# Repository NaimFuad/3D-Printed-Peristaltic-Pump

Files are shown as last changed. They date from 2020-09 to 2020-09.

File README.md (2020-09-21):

# 3D-Printed-Peristaltic-Pump
3D printed peristaltic pump intended for precise dosing of liquid

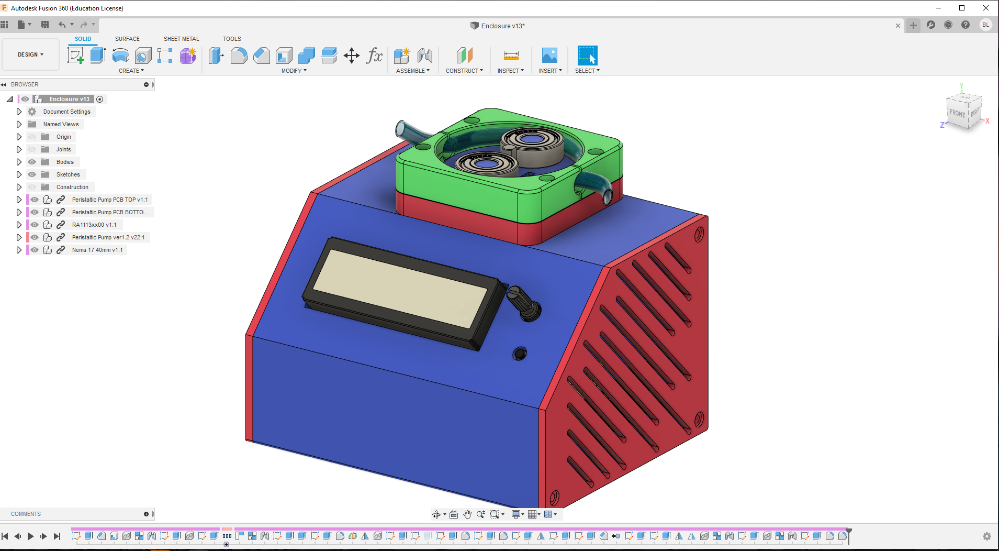
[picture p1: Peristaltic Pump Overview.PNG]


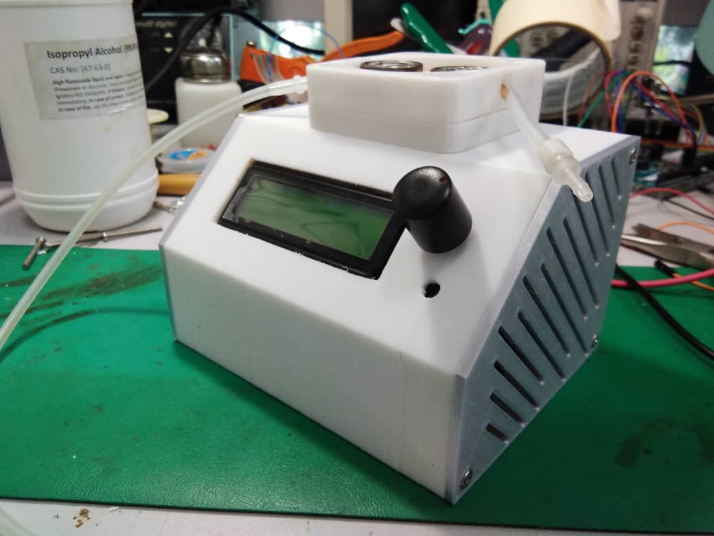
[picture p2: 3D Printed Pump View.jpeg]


[Video on how it work](https://youtu.be/wXhuivK0bVU)

Status - Work In Progress

The main idea of this project is to allow user to 3D print their own peristaltic pump. The pump able to micro dose liquid and the design allows it to self prime and avoid from bleeding.

An extension of this project can be applied to agricultural field where precise chemical might need to be introduce to plant from time to time.

## Hardware

* Frame - 3D Printed
* 608ZZ Bearing
* M3 Screw
* M3 Treaded Insert

## Electronics
* NEMA 17 Stepper Motor
* PCB - Fabricated from JLCPCB - footprint selected to allow user to hand solder
* A4988 Stepper Motor Driver
* etc. Refer to Bill of Material provided 

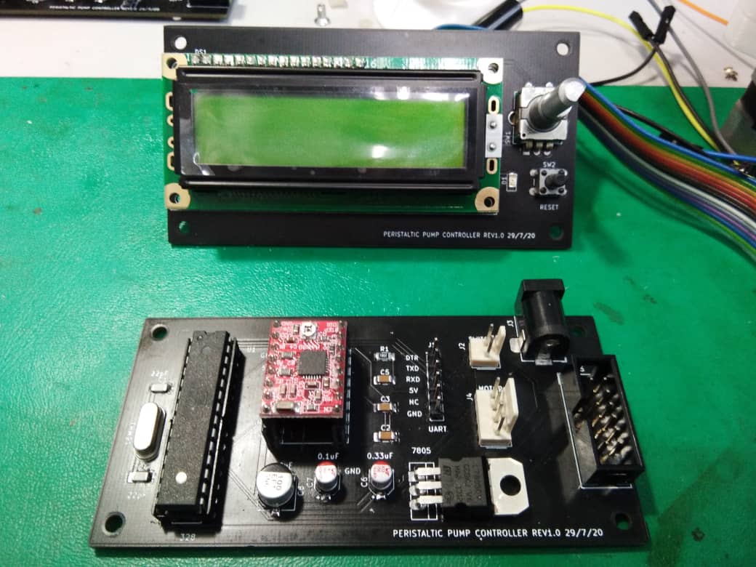
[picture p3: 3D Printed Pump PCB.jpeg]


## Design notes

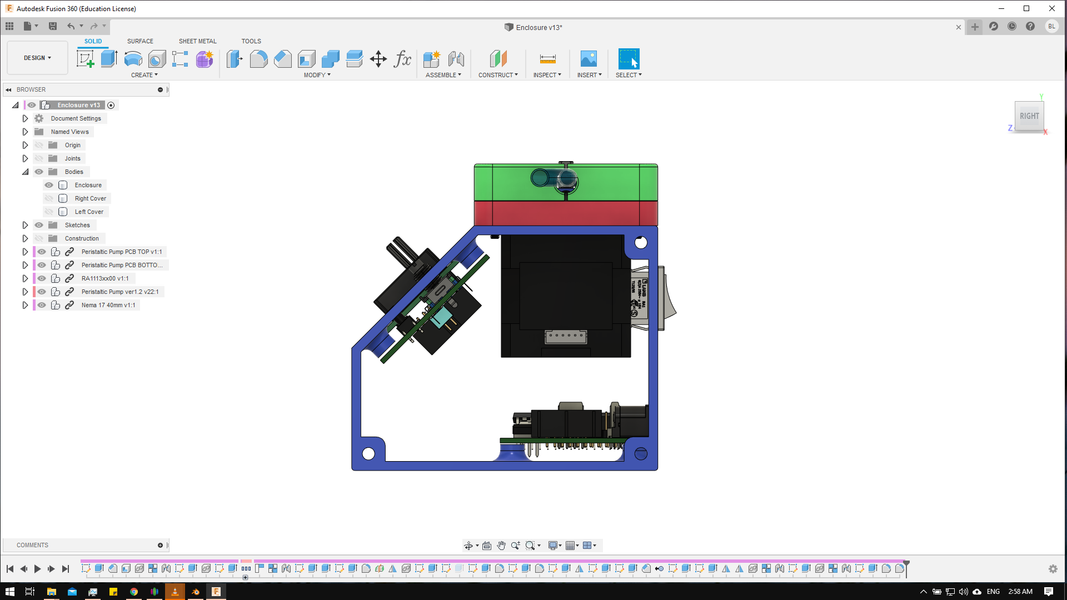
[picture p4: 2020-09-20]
Peristaltic Pump Sideview.PNG

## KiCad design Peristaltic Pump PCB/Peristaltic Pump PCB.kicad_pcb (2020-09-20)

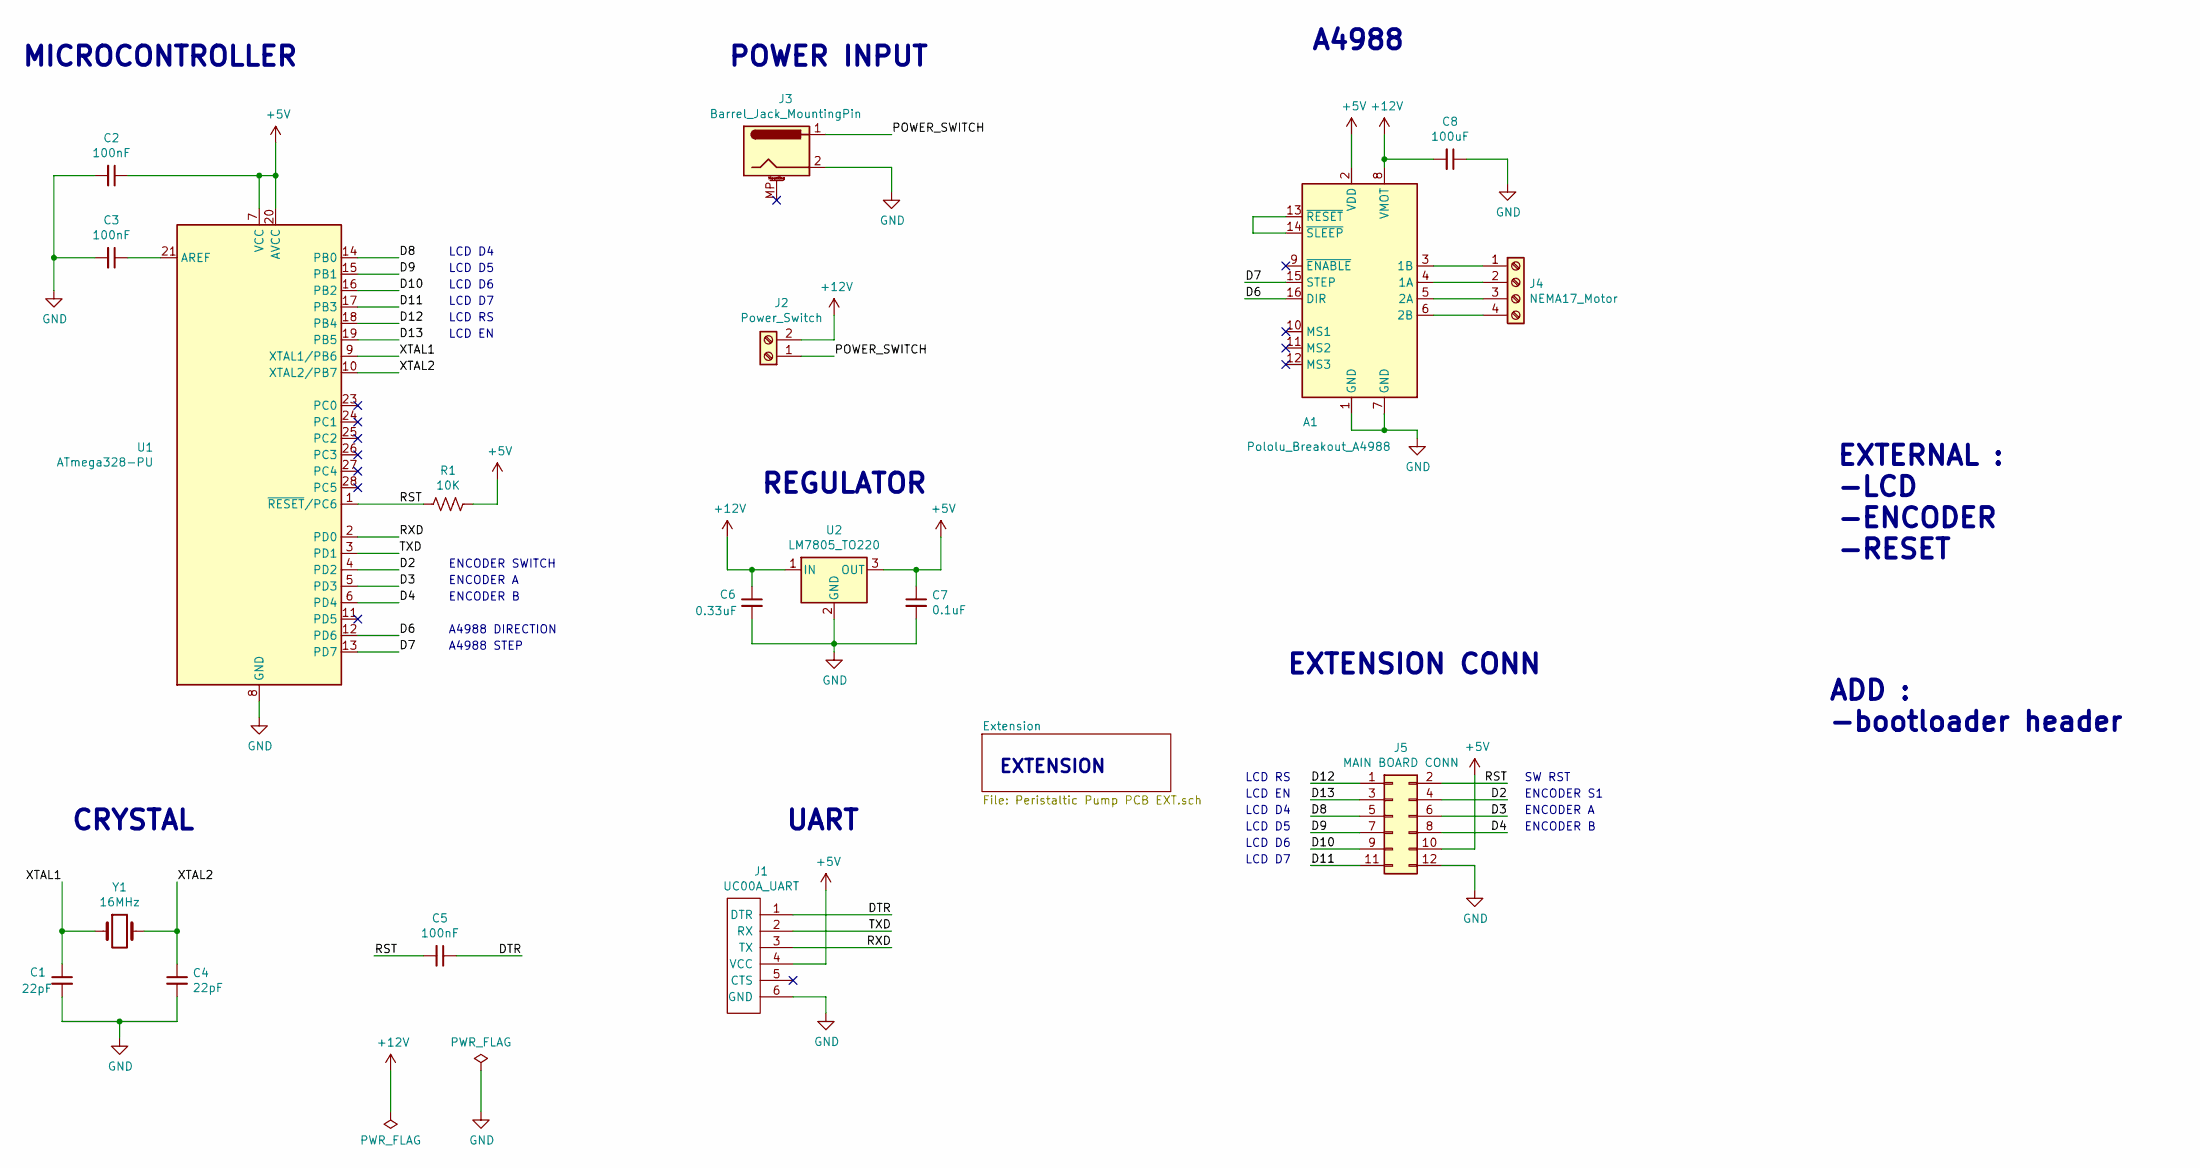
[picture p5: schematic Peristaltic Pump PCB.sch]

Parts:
A1: Pololu_Breakout_A4988; Pololu_Breakout-16_15.2x20.3mm
C1, C4: 22pF; C_1206_3216Metric_Pad1.42x1.75mm_HandSolder
C2, C3, C5: 100nF; C_1206_3216Metric_Pad1.42x1.75mm_HandSolder
C6: 0.33uF; CP_Elec_4x5.4
C7: 0.1uF; CP_Elec_4x5.4
C8: 100uF; CP_Elec_6.3x5.8
J1: UC00A_UART; Pin_Header_Straight_1x06_Pitch2.54mm
J2: Power_Switch; Molex_KK-254_AE-6410-02A_1x02_P2.54mm_Vertical
J3: Barrel_Jack_MountingPin; BarrelJack_Horizontal
J4: NEMA17_Motor; Molex_KK-254_AE-6410-04A_1x04_P2.54mm_Vertical
J5: MAIN BOARD CONN; IDC-Header_2x06_P2.54mm_Vertical
R1: 10K; R_1206_3216Metric_Pad1.42x1.75mm_HandSolder
U1: ATmega328-PU; DIP-28_W7.62mm
U2: LM7805_TO220; TO-220-3_Vertical
Y1: 16MHz; Crystal_HC49-4H_Vertical

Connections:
+5V: A1.2 (VDD), C2.1, C7.1, J1.4 (VCC), J5.10, R1.1, U1.7 (VCC), U1.20 (AVCC), U2.3 (OUT)
+12V: A1.8 (VMOT), C6.1, C8.2, J2.2, U2.1 (IN)
/D2: J5.4, U1.4 (PD2)
/D3: J5.6, U1.5 (PD3)
/D4: J5.8, U1.6 (PD4)
/D6: A1.16 (DIR), U1.12 (PD6)
/D7: A1.15 (STEP), U1.13 (PD7)
/D8: J5.5, U1.14 (PB0)
/D9: J5.7, U1.15 (PB1)
/D10: J5.9, U1.16 (PB2)
/D11: J5.11, U1.17 (PB3)
/D12: J5.1, U1.18 (PB4)
/D13: J5.3, U1.19 (PB5)
/DTR: C5.1, J1.1 (DTR)
/POWER_SWITCH: J2.1, J3.1
/RST: C5.2, J5.2, R1.2, U1.1 (~RESET~/PC6)
/RXD: J1.3 (TX), U1.2 (PD0)
/TXD: J1.2 (RX), U1.3 (PD1)
/XTAL1: C1.1, U1.9 (XTAL1/PB6), Y1.1
/XTAL2: C4.1, U1.10 (XTAL2/PB7), Y1.2
GND: A1.1 (GND), A1.7 (GND), C1.2, C2.2, C3.2, C4.2, C6.2, C7.2, C8.1, J1.6 (GND), J3.2, J5.12, U1.8 (GND), U1.22 (GND), U2.2 (GND)
unnamed: A1.3 (1B), J4.1
unnamed: A1.4 (1A), J4.2
unnamed: A1.5 (2A), J4.3
unnamed: A1.6 (2B), J4.4
unnamed: A1.13 (~RESET), A1.14 (~SLEEP)
unnamed: C3.1, U1.21 (AREF)

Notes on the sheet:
UART
POWER INPUT
CRYSTAL
REGULATOR
A4988 STEP
A4988 DIRECTION
ENCODER A
ENCODER B
ENCODER SWITCH
A4988
EXTERNAL : -LCD -ENCODER -RESET
LCD RS
LCD EN
LCD D7
LCD D6
LCD D5
LCD D4
MICROCONTROLLER
EXTENSION CONN
SW RST
ENCODER S1
EXTENSION
ADD : -bootloader header

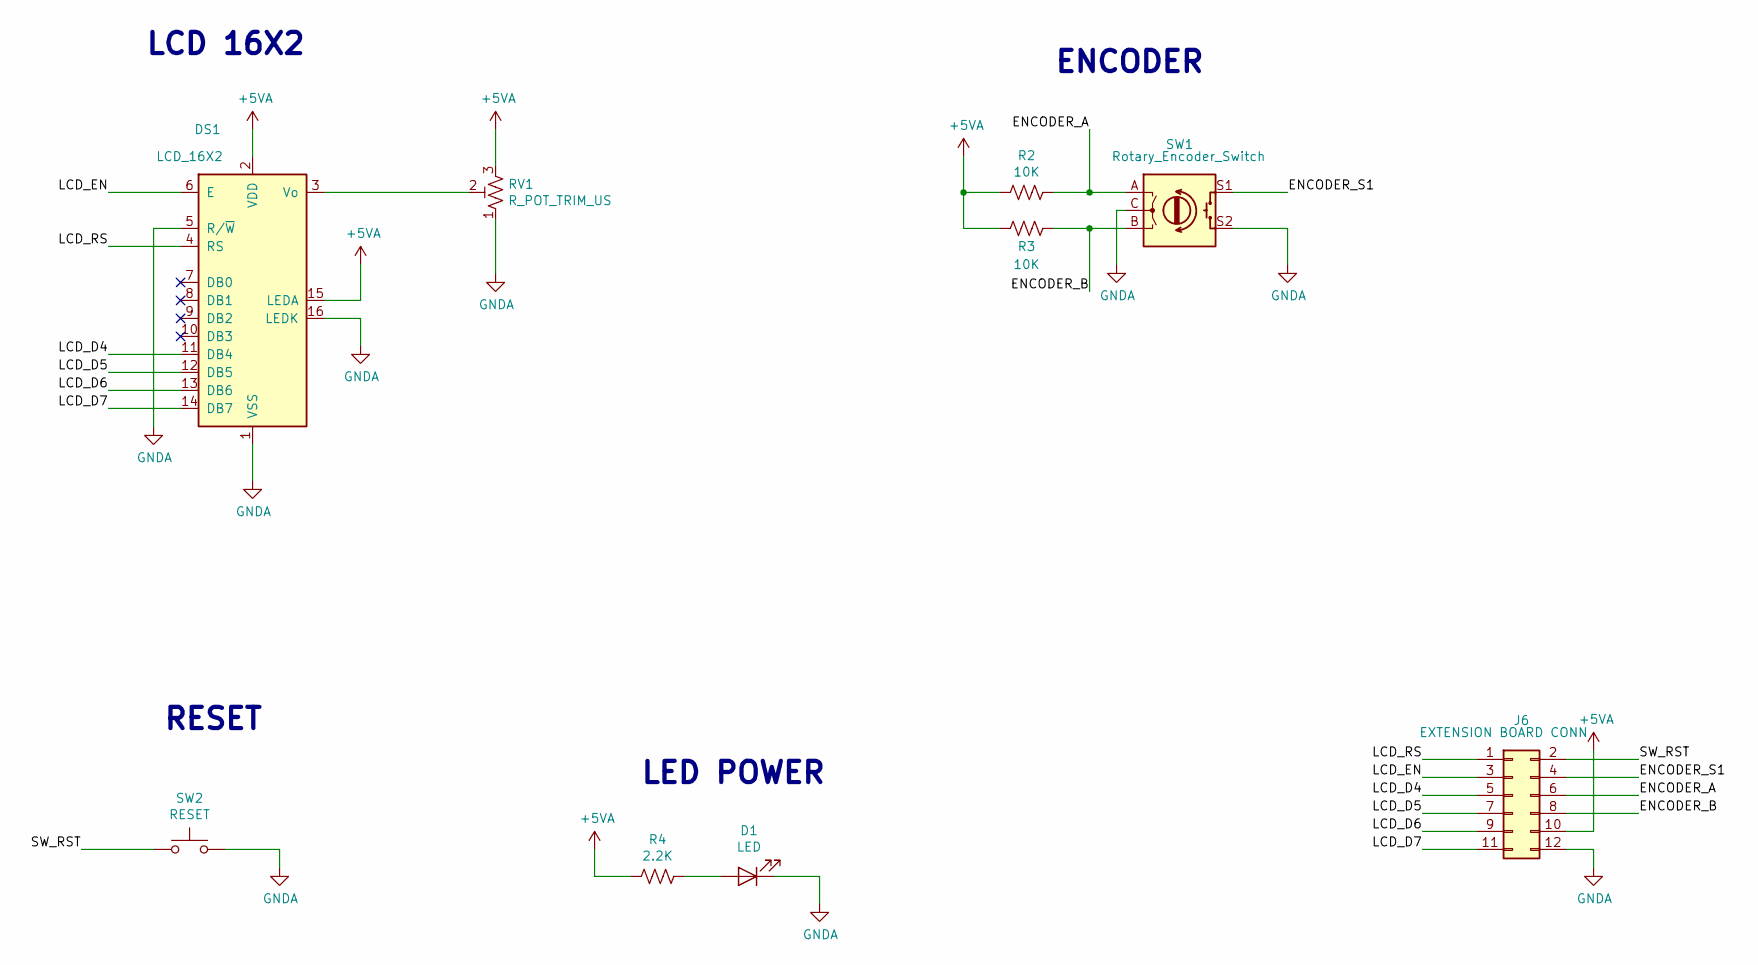
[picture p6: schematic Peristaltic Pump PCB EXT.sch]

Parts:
D1: LED; LED_1206_3216Metric_Pad1.42x1.75mm_HandSolder
DS1: LCD_16X2; WC1602A
J6: EXTENSION BOARD CONN; IDC-Header_2x06_P2.54mm_Vertical
R2, R3: 10K; R_1206_3216Metric_Pad1.42x1.75mm_HandSolder
R4: 2.2K; R_1206_3216Metric_Pad1.42x1.75mm_HandSolder
RV1: R_POT_TRIM_US; Potentiometer_Vishay_T73YP_Vertical
SW1: Rotary_Encoder_Switch; RotaryEncoder_Alps_EC11E-Switch_Vertical_H20mm_CircularMoun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
SW2: RESET; SW_PUSH_6mm

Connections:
+5VA: DS1.2 (VDD), DS1.15 (LEDA), J6.10, R2.2, R3.2, R4.2, RV1.3
/Extension/ENCODER_A: J6.6, R2.1, SW1.A
/Extension/ENCODER_B: J6.8, R3.1, SW1.B
/Extension/ENCODER_S1: J6.4, SW1.S1
/Extension/LCD_D4: DS1.11 (DB4), J6.5
/Extension/LCD_D5: DS1.12 (DB5), J6.7
/Extension/LCD_D6: DS1.13 (DB6), J6.9
/Extension/LCD_D7: DS1.14 (DB7), J6.11
/Extension/LCD_EN: DS1.6 (E), J6.3
/Extension/LCD_RS: DS1.4 (RS), J6.1
/Extension/SW_RST: J6.2, SW2.1
GNDA: D1.1 (K), DS1.1 (VSS), DS1.5 (R/~W), DS1.16 (LEDK), J6.12, RV1.1, SW1.C, SW1.S2, SW2.2
unnamed: D1.2 (A), R4.1
unnamed: DS1.3 (Vo), RV1.2

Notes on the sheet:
LCD 16X2
RESET
ENCODER
LED POWER

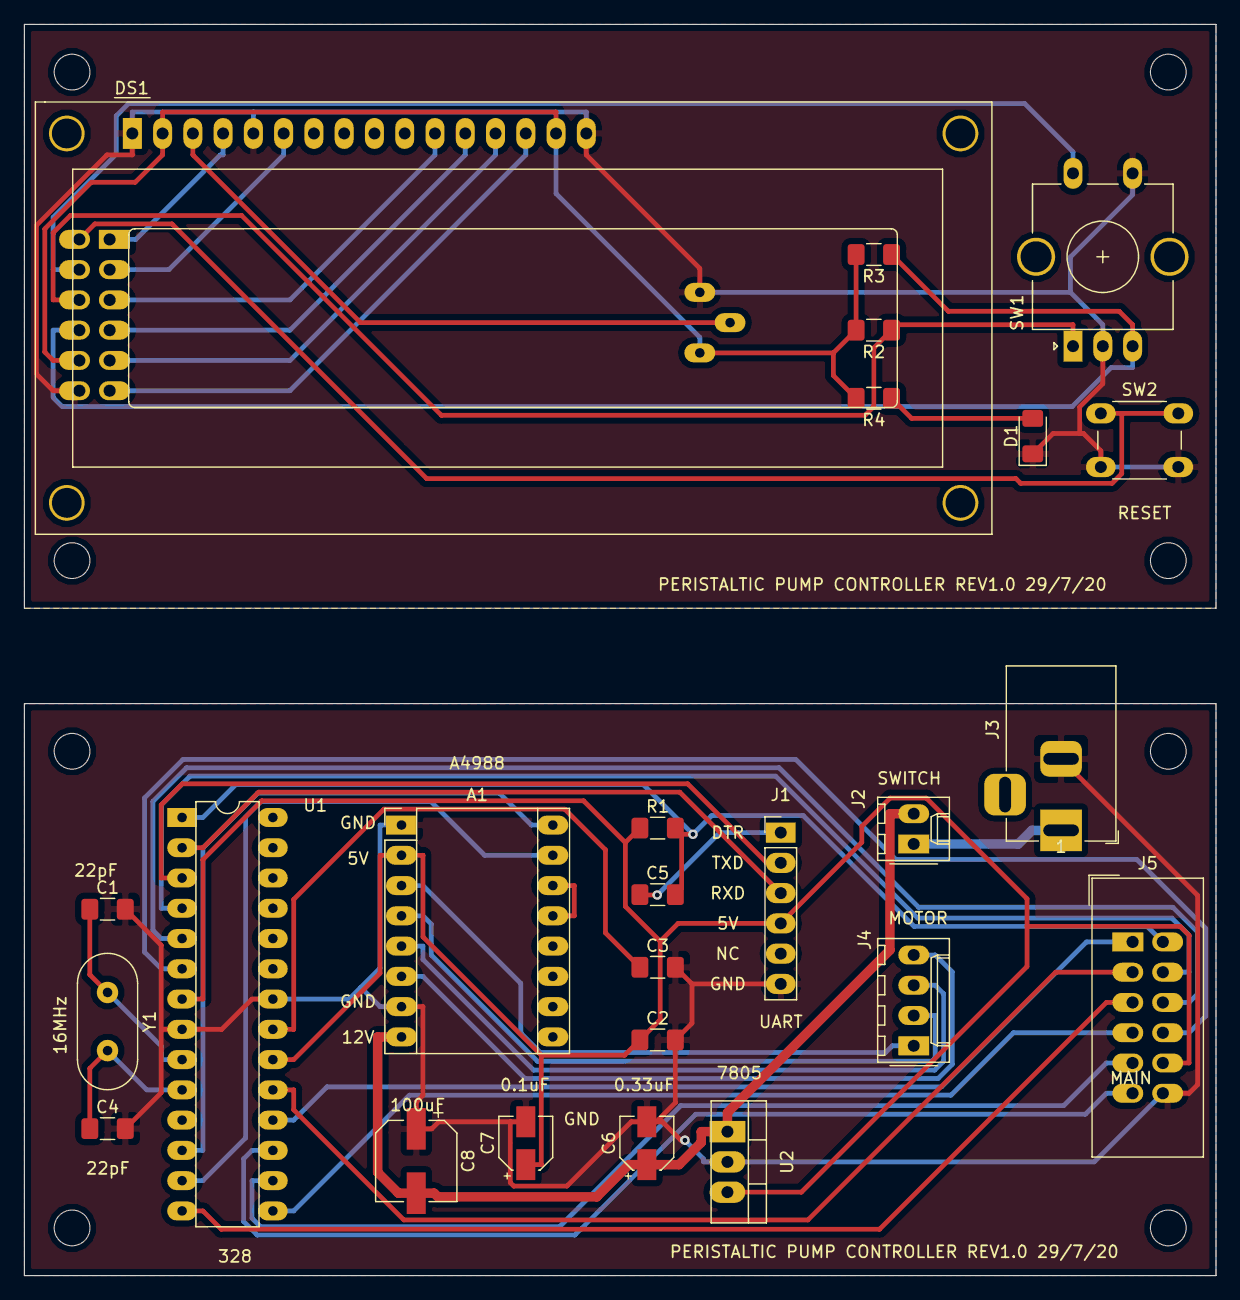
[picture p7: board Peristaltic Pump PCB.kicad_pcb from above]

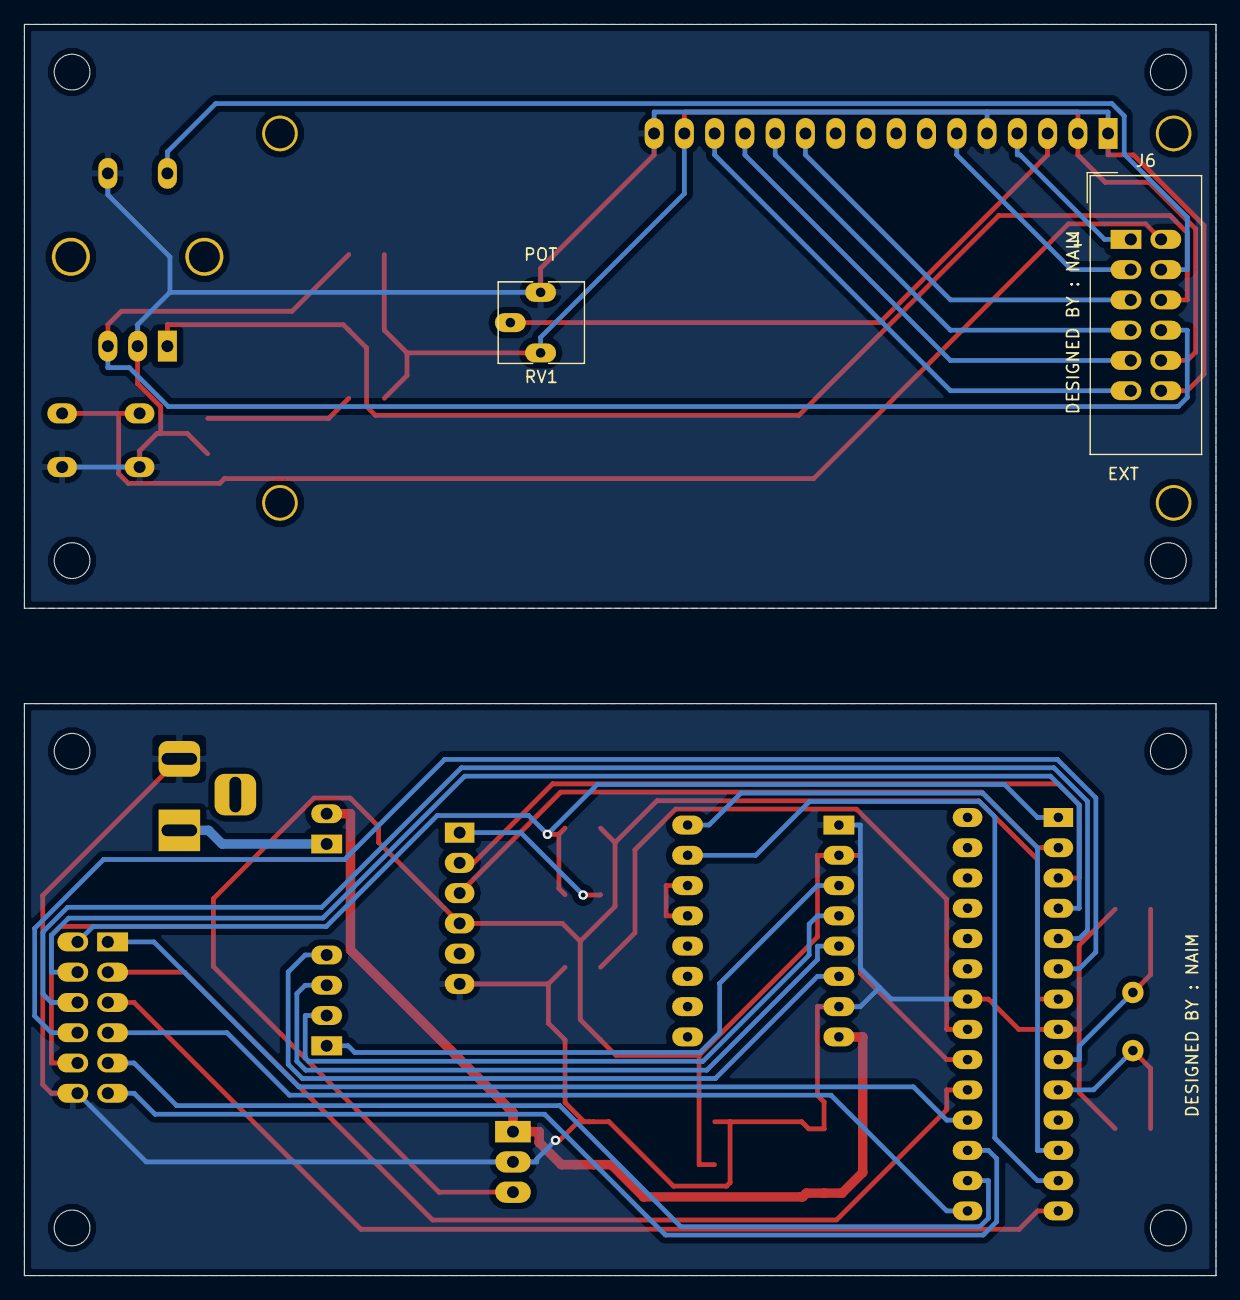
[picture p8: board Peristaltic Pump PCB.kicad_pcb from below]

Board: 2 copper layers, 100.0 x 105.0 mm, 35 parts (2 on the bottom side), 41 nets.

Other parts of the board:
MT1, MT2, MT3, MT4, MT5, MT6, MT7, MT8: MountingHole_3mm
